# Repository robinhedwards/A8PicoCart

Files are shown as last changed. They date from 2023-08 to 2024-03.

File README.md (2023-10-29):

# A8PicoCart (UnoCart on a Raspberry Pi Pico clone)

The A8PicoCart is a multi-cart for the Atari 8-bit (XL/XE) which you can make at home with only basic soldering skills.
It is based on my earlier UnoCart design but uses a very inexpensive Raspberry Pi Pico clone (£2-3) for an easy build.

When plugged into a PC by USB it becomes a Mass Storage device allowing ROM/CAR/XEX & ATR files to be copied to the cartridge.
When plugged into an Atari these files are shown on the menu and the device will either emulate the selected cartridge type or
act as a XEX file launcher. It also has (very) limited support for ATR files allowing you to do some programming and save your
work to an ATR file.

This page contains everything you need to build the project - firmware to flash to your purple Pico clone, Kicad PCB design files to make a PCB and 3d print files for a nice case. The source code for everything is also here. There is also a manual detailing the full capabilities of the cartridge.

If you build an A8PicoCart consider donating to help fund this and my future projects:



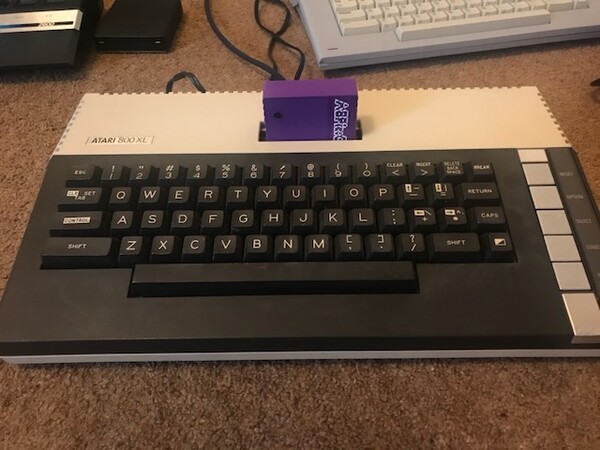
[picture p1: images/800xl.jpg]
Cased A8PicoCart in a 800xl

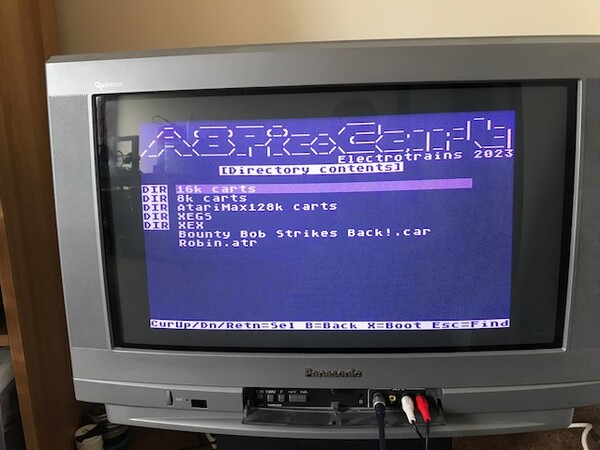
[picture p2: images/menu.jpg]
A8PicoCart Menu


## Quick Start

Get yourself a purple Raspberry Pi Pico clone (see [this thread](https://forums.raspberrypi.com/viewtopic.php?t=337976) for details) and order a PCB using the KiCad board files provided. You have a choice of two PCB designs - the XE design is for use uncased, with the Pico on the top surface. The XL/XE version is desgined to be mounted in a case (though can be used uncased too) with the Pico on the bottom/back surface. Once you have the Pico clone and PCB, solder the pico as pictured below, depending on your PCB version. Program the firmware onto the device by pressing BOOTSEL on the board and connecting to USB on a PC and drag the firmware (UF2 file) onto the device. It should then remount as A8-PICOCART so you can copy Atari CAR & XEX files to it. Unmount, then plug into your Atari and play! Optionally solder a reset button to reset back to the menu.

**Warning**: always disconnect from PC/USB before plugging into your Atari or you will damage your Atari and/or PC. This warning mainly
applies to the XE/uncased version of the PCB. The newest version of the XL/XE board makes it physically impossible to connect USB when the
cartridge is inserted in an Atari.

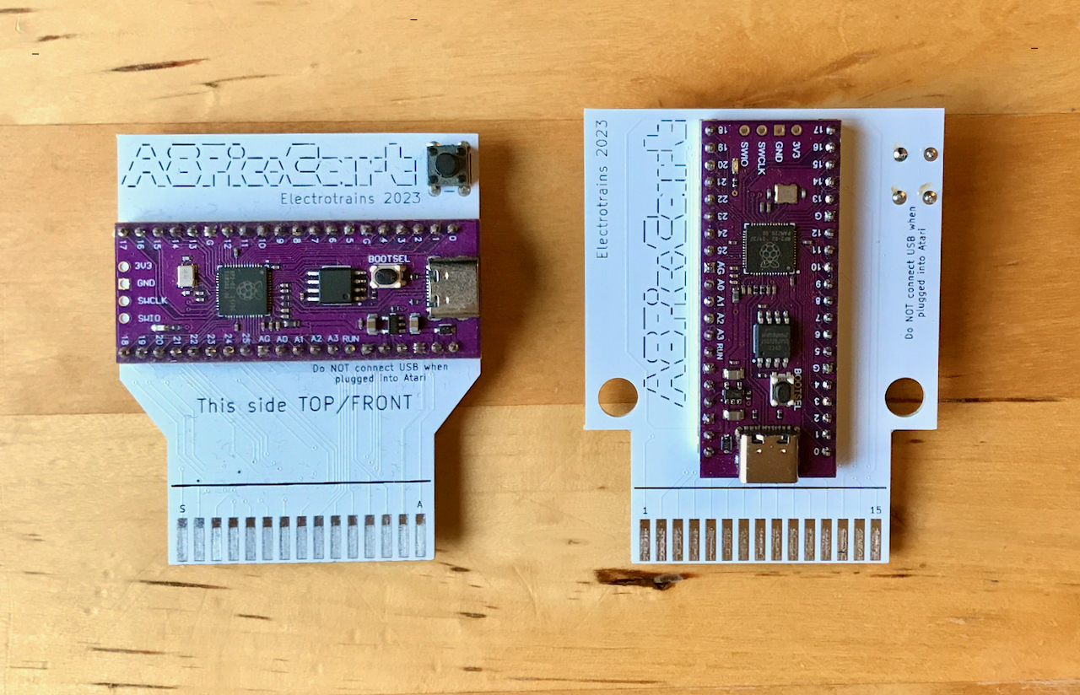
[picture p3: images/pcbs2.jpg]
Purple Pico mounted on the PCBs

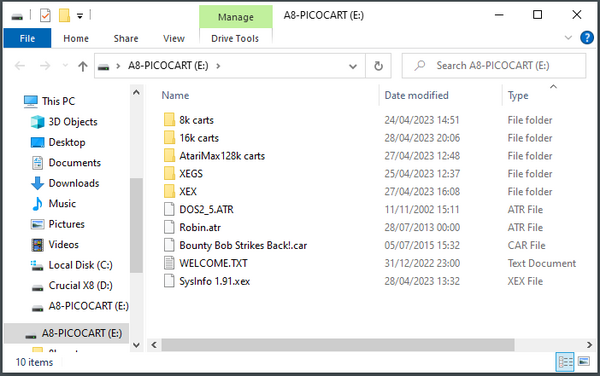
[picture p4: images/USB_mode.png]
USB Mass Storage mode


## Inserting the cartridge

Depending on which PCB you choose the Pico clone may be mounted on the front or back of the PCB. When you insert
the cartridge in the Atari make sure the "S..A" side of the cartridge edge (NOT the "1..15" side) is facing upwards (XE) or towards you (XL).

## Purple Pico clones

The firmware is designed for the Purple Pico clones with USB C connector and 16Megs of flash and a single button (BOOTSEL).
I've received these devices with two different types of SPI flash chips - Winbond and (slower) Z-bit. The firmware has been tested with both types.

The project defines a custom board with a higher value for PICO_FLASH_SPI_CLKDIV so it supports the slower Z-bit flash.

Be aware that it's possible you might get one with another type of flash memory chip that has not been tested.

## Reset button

You can solder a push button to the cartridge to get back to the menu and avoid wear on your Atari power switch.
When you reset the cartridge the Atari will crash - just push reset on the Atari itself to get back to the menu.

The button used is a 6x6mm thru-hole tactile momentary switch. If you are going to print a case, then 9mm+ height is suitable.
When you solder the button to the PCB - make sure the lower two holes in the PCB are bridged only when the button is pressed.

It works simply by pulling the RUN pin on the pico clone to ground to reset.

## 3D print files

The STL files can be used to print a 3 part (front, back and logo) cartridge shell. The 2-tone logo is achieved by
changing the filament at the correct z-position when printing a8pico_logo.stl. You'll also need two M3 15mm screws.

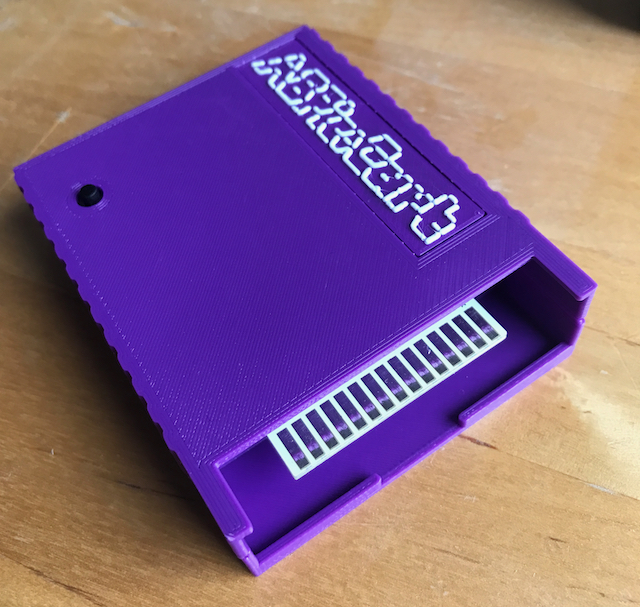
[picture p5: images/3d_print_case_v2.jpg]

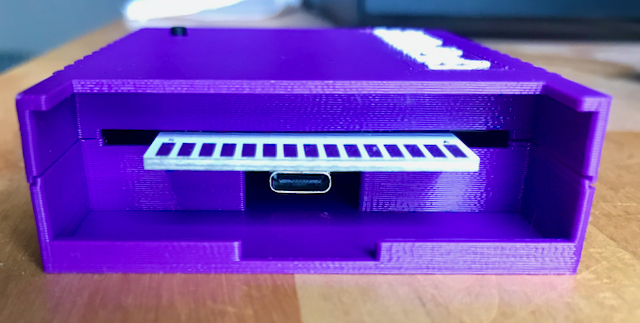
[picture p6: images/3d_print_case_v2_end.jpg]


## Changelog

* 7 Oct 2023 - Add new PCB & case design files to make it impossible to insert USB when plugged into Atari. Add support for Microcart (CAR type 52) cartridges. Updated manual.
* 29 Oct 2023 - Adds 3 new cartridge types (thanks to ascrnet)

## Credits

* Design, hardware and firmware by Robin Edwards (electrotrains at atariage)
* XEX loader and OS modifications by Jonathan Halliday (flashjazzcat at atariage)
* Altirra LLE OS used with permision from Avery Lee (phaeron at atariage)

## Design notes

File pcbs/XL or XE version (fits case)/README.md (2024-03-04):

## XL/XE version PCB (which fits the 3d printed case design)

* KiCad Project
* A zip file of the gerbers (Elecrow specification).
* Updated version for pico pointing downwards towards cartridge slot

PCB specifications:
1.6mm thickness
Hard gold fingers with bevelled edge will make your PCB last longer, but at a much higher cost.

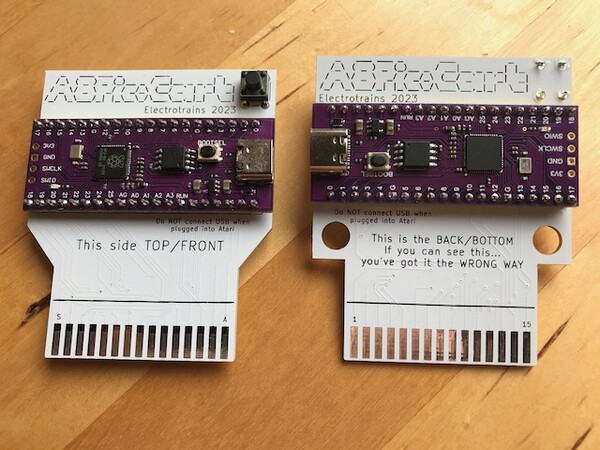
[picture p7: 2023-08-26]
images/pcbs.jpg

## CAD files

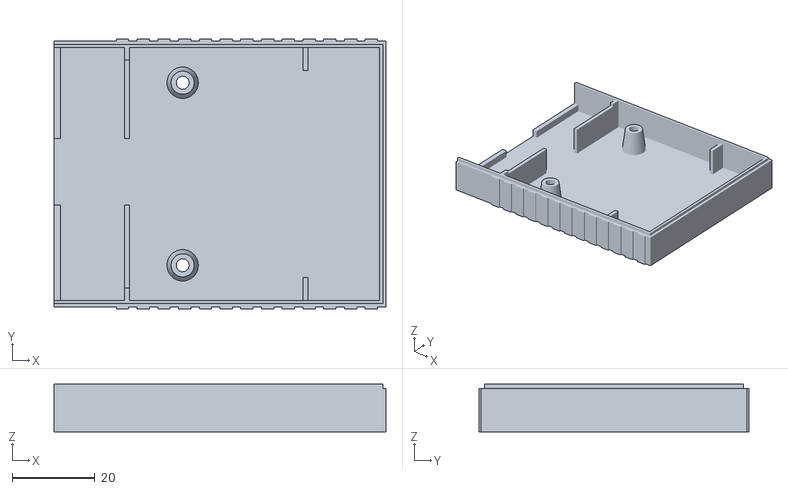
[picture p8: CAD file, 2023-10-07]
cartridge shell 3d print files/a8pico_back_v2.stl
80.0 x 65.0 x 11.5

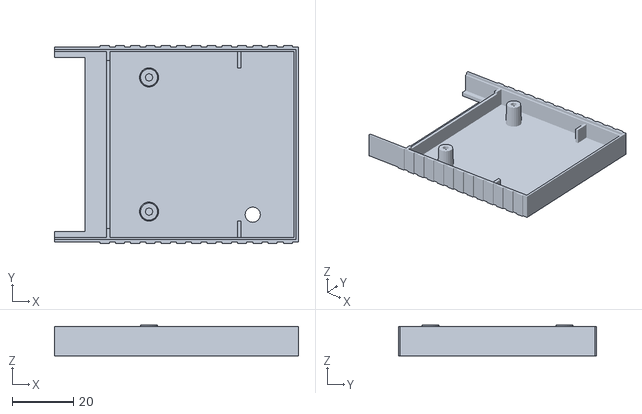
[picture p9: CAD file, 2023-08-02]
cartridge shell 3d print files/a8pico_front.stl
80.0 x 65.0 x 10.1

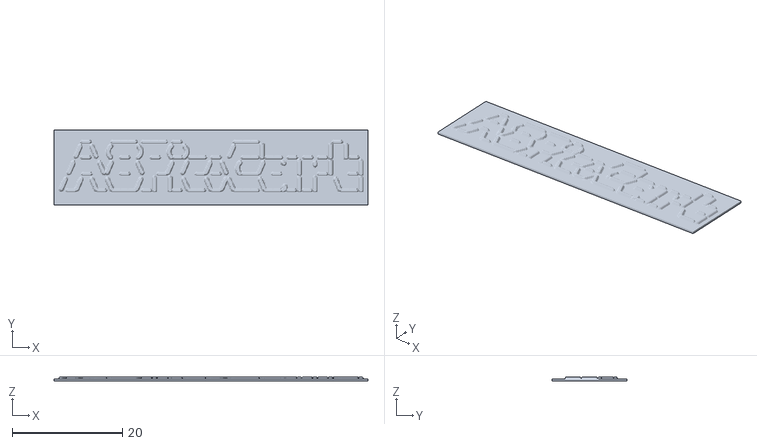
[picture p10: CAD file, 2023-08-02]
cartridge shell 3d print files/a8pico_logo.stl
57.0 x 13.7 x 0.8

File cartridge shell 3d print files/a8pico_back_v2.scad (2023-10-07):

/* A8PicoCart shell
   (c) R.Edwards 2023
*/

ridge_width = 0.5;
cart_length=80;
cart_width=65 - (ridge_width*2);
cart_height=11.5;
screw_sep = 44;
front_thickness = 1.6;
sides_thickness = 1.6 - 0.05;
support_thickness = 1.2 - 0.05;
support_height = 10.5;
rim_height=1;

difference() {
    union() {
        difference() {
            // main shell
            union() {
                cube([cart_length, cart_width, cart_height-rim_height]);
                // rim
                translate([0, sides_thickness/2, cart_height-rim_height])
                    cube([cart_length-sides_thickness/2, sides_thickness/2, rim_height]);
                translate([0, cart_width-sides_thickness, cart_height-rim_height])
                    cube([cart_length-sides_thickness/2, sides_thickness/2, rim_height]);
                translate([cart_length-sides_thickness, sides_thickness/2, cart_height-rim_height])
                    cube([sides_thickness/2, cart_width-sides_thickness, rim_height]);
            }
            // make hollow
            translate([0, sides_thickness, front_thickness])
                cube([cart_length-sides_thickness,
                    cart_width-sides_thickness*2,
                    cart_height-front_thickness]);
        }    
        // end
        cube([sides_thickness, cart_width, 4]);
        // pcb supports
        difference() {
            translate([17, sides_thickness, 0])
                cube([support_thickness, cart_width-sides_thickness*2, cart_height]);
            translate([17, (cart_width-55)/2, support_height])
                cube([support_thickness, 55, cart_height-support_height]);
        }
        translate([60, 0, 0])
            cube([support_thickness, 7, support_height]);
        translate([60, cart_width-7, 0])
            cube([support_thickness, 7, support_height]);
        // screw holes
        translate([31, (cart_width-screw_sep)/2, 0])
            difference() {
                cylinder(h = support_height - 1.2, r1 = 4, r2 = 2.8,  $fs = 1);
                cylinder(h = support_height - 1.2, r1 = 1.6, r2 = 1.6,  $fs = 1);
            }
        translate([31, cart_width-(cart_width-screw_sep)/2, 0])
            difference() {
                cylinder(h = support_height - 1.2, r1 = 4, r2 = 2.8,  $fs = 1);
                cylinder(h = support_height - 1.2, r1 = 1.6, r2 = 1.6,  $fs = 1);
            }
        // ridges
        for (i = [15: 5: cart_length-5])
            union() {
                translate([i, -ridge_width, 0])
                    cube([3, ridge_width, cart_height-rim_height]);
                translate([i, cart_width, 0])
                    cube([3, ridge_width, cart_height-rim_height]);
            }
    }
    // screw head
    translate([31, (cart_width-screw_sep)/2, 0])
        cylinder(h = 0.6, r1 = 3.5, r2 = 3.5,  $fs = 1);
    translate([31, (cart_width-screw_sep)/2, 0.6])
        cylinder(h = front_thickness-0.6, r1 = 3.5, r2 = 1.8,  $fs = 1);

    translate([31, cart_width-(cart_width-screw_sep)/2, 0])
        cylinder(h = 0.6, r1 = 3.5, r2 = 3.5,  $fs = 1);
    translate([31, cart_width-(cart_width-screw_sep)/2, 0.6])
        cylinder(h = front_thickness-0.6, r1 = 3.5, r2 = 1.8,  $fs = 1);
     // cutout USB slot
    translate([0, (cart_width-16)/2+0.5, front_thickness])    // pico is 0.5 mm off center
        cube([40, 16, cart_height]);

}

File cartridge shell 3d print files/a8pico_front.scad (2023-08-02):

/* A8PicoCart shell
   (c) R.Edwards 2023
*/

ridge_width = 0.5;
cart_length=80;
cart_width=65 - (ridge_width*2);
cart_height=9.6;
screw_sep = 44;
front_thickness = 1.6;
sides_thickness = 1.6 - 0.05;
support_thickness = 1.2 - 0.05;
support_height = 7.6;
rim_height = 1;
logo_width = 14.5;
logo_height = 58;

difference() {
    union() {
        difference() {
            // main shell
            cube([cart_length, cart_width, cart_height]);
            // rims
            translate([0, sides_thickness/2, cart_height-rim_height])
                cube([cart_length-sides_thickness/2,
                    cart_width-sides_thickness, rim_height]);
            // make hollow
            translate([0, sides_thickness, front_thickness])
                cube([cart_length-sides_thickness,
                    cart_width-sides_thickness*2,
                    cart_height-front_thickness]);
            // cutout cart port
            translate([0, (cart_width-57)/2, 0])
                cube([10, 57, cart_height]);
            // button
            translate([cart_length-15, 9, 0])
               cylinder(h = front_thickness, r1 = 2.5, r2 = 2.5,  $fs = 1); 
        }    
        // pcb supports
        difference() {
            translate([17, 0, 0])
                cube([support_thickness, cart_width, cart_height-rim_height]);
            translate([17, (cart_width-55)/2, support_height])
                cube([support_thickness, 55, cart_height-support_height]);
        }
        translate([60, 0, 0])
            cube([support_thickness, 7, support_height]);
        translate([60, cart_width-7, 0])
            cube([support_thickness, 7, support_height]);
        // screw holes
        translate([31, (cart_width-screw_sep)/2, 0])
            difference() {
                cylinder(h = support_height + 2.5, r1 = 3.2, r2 = 2.8,  $fs = 1);
                cylinder(h = support_height + 2.5, r1 = 1.25, r2 = 1.25,  $fs = 1);
            }
        translate([31, cart_width-(cart_width-screw_sep)/2, 0])
            difference() {
                cylinder(h = support_height + 2.5, r1 = 3.2, r2 = 2.8,  $fs = 1);
                cylinder(h = support_height + 2.5, r1 = 1.25, r2 = 1.25,  $fs = 1);
            }
        // ridges
        for (i = [15: 5: cart_length-5])
            union() {
                translate([i, -ridge_width, 0])
                    cube([3, ridge_width, cart_height]);
                translate([i, cart_width, 0])
                    cube([3, ridge_width, cart_height]);
            }
    }
    // logo space
    translate([cart_length-logo_height-2, cart_width-logo_width-3.5, 0])
        cube([logo_height, logo_width, 1]);
}

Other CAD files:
cartridge shell 3d print files/Previous Versions/a8pico_back.stl
cartridge shell 3d print files/a8pico_back.stl
cartridge shell 3d print files/a8pico_back.scad
cartridge shell 3d print files/Previous Versions/a8pico_back.scad

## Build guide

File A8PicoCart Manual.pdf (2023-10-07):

# Instruction Manual

Revision 3 30/9/2023

Atari XL/XE multi-cart

1

## Quick Start

The A8PicoCart is a cartridge emulator and XEX file launcher for Atari XL & XE machines supporting cartridge images and files up to 128k in size. It is a reworking of the UnoCart design for the Raspberry Pi Pico hardware.
When plugged into a PC using a USB C cable, it will appear as a USB Mass Storage device called A8-PICOCART allowing you to easily copy new Atari software to the cartridge. It has 15megs of flash storage available for Atari files.
*ALWAYS REMOVE THE CARTRIDGE FROM YOUR ATARI BEFORE PLUGGING IN A USB CABLE* Copy XEX, CAR and ROM files to the cartridge from your PC. You can create folders to organize the files. Eject the USB storage device from your PC before disconnecting the cable. Insert the cartridge in the Atari 8-bit. If the board is uncased, look for the text on the board indicating the correct orientation – the reset button should be facing forwards (Atari XL) or upwards (Atari XE). After switching on your Atari, you should see the cartridge menu screen. Use the cursor up and down keys to select an item and press Return to start it.

## Menu

The menu allows you to navigate the files on the built-in flash memory and select a title to use. Use the cursor up, down and [Return] keys to select items. Press [B] to go back to the parent directory. Press [ESC] to search for a file. Press [X] to disable the cartridge and boot normally (e.g. from a SIO device) – this allows you to leave the cartridge plugged in.

## Reset Button

Press the reset button to reset the cartridge. This will generally cause the Atari to crash, and the reset button on the Atari can then be pressed to return to the cartridge menu.

## Reset Filesystem

In the event the on-board filesystem becomes corrupted, you can reset it by holding the fire button on the first Atari joystick when you power on the Atari. Press Y in response to the prompt offering to reset the flash memory. The device will now be in a “factory” state when next used as a USB mass storage device.

## CAR Files & ROM Files

CAR files and ROM files both contain the data for a cartridge. However CAR files have an additional 16 bytes header containing the cartridge type making it clearly identifiable to the A8PicoCart. In contrast, the cartridge type of a ROM file is ambiguous – e.g. an 8k ROM file could be a standard 8K cartridge, or an 8k OSS cartridge.

## ROM Files

Plain ROM files are supported, but since these files are raw cartridge dumps, the A8PicoCart will decide what type of cartridge they come from based on the file size only. The table below shows what types will be used.
ROM File Size | Cartridge Type
8k | Standard Atari 8k
16k | Standard Atari 16k
32k | Atari XEGS 32k
64k | Atari XEGS 64k
128k | Atari XEGS 128k

2

## Supported Cartridge Types (CAR files)

Description | CAR Type(s)
Standard Atari 8k | 1
Standard Atari 16k | 2
Atari XEGS 32-128k | 12-14
AtariMax 1mbit (128k) | 41
Switchable XEGS 32-128k | 33-35
Megacart 16-128k | 26-29
Bounty Bob | 18
Williams 32k, 64k | 8, 22
OSS 8k | 44
OSS 16k (034M) | 3
OSS 16k (043M) | 45
OSS 16k (type B) | 15
SIC!Cart (128k only) | 54
SDX 64k | 11
Diamond 64k | 10
Express 64k | 9
SDX 128k | 43
Blizzard 16k | 40
4k | 58
Turbosoft 64k, 128k | 50, 51
ATRAX 128k | 17
MicroCalc/Ultracart 32k | 52

## Converting to CAR format

Utilities are available to convert ROM/BIN files into the CAR file format. The ROM2CAR utility available on the Ultimate cart website provides an easy drag and drop interface: https://github.com/robinhedwards/UltimateCart/

## Problem Files

You may come across files with a .BIN extension. These are often just .ROM files and can be renamed. You may also find ROM files where the A8PicoCart menu gives the error “Unsupported ROM size”. This happens when the ROM file is not an exact multiple of 1,024 bytes. In this case, the ROM dump may have already been converted to a CAR file (with a 16 byte header) but has been wrongly named and you can simply rename the file from .ROM to .CAR.

## ATR Files (64k and above XL/XE only)

The cartridge also has simple support for reading and writing to ATR (floppy disk image) files. It supports both SD (128 byte sector) and DD (256 byte sector) images. DD images must be standard ATR files, with 128 bytes for the first 3 sectors and no padding. The device supports ATR files up to 15 megabytes in size.
When an ATR file is selected from the menu, a modified version of the Atari operating system (OS), based on the Altirra open-source LLE kernel, is installed as a “soft” OS in the 16k RAM under the OS – this allows the Atari’s SIO requests to disk drive 1 (D1:) to be re-directed to the SD card in the cartridge.
The main use case for this feature is to allow you to boot a DOS formatted disk (e.g. DOS 2.5) and load and save BASIC programs to the disk. Note that the A8PicoCart cannot emulate a disk and cartridge at the same time.

3

Accesses to other disk drives (D2: upwards) are passed through to the SIO port as normal. This allows files to be copied between an ATR mounted on the cartridge (D1:) and other SIO devices (D2:+).
Hold down OPTION when you select the ATR file to disable BASIC. This is necessary for many games. MyPicoDOS ATRs will run, but SELECT should be pressed to disable high-speed SIO, and use the operating system SIO routines instead.
Important note – many ATRs will run correctly from the A8PicoCart. However, any programs that attempt to use the RAM under OS will not work, nor will any software that does not use the standard OS SIO calls.
The OS ROM is stored in the cartridge firmware, but an alternative UNO_OS.ROM file (16k) will be loaded and installed from the root directory of the SD card instead (if such a file is present).

## Firmware re-programming (advanced)

To program a new version of the firmware to the cart, first unscrew the cartridge shell (if present) to reveal the PCB inside. There should be a single button on the purple Pico board, marked BOOTSEL. Press and hold this button as you connect the cartridge to your PC with your USB cable. The cartridge will mount as a mass storage device, but instead of showing up as a A8-PICOCART, it should instead show as a device labelled RPI-RP2.
You can reprogram the Raspberry Pi by dragging a UF2 file into the explorer window. When the new firware has been programmed the device will dissappear, and remount as an A8-PICOCART with all files still present. The latest firmware is available on the project website: https://github.com/robinhedwards/A8PicoCart

## Microcontroller (advanced)

The A8PicoCart uses a clone of the Raspberry Pi Pico that differs from the official board by having all the RP2040 GPIO pins broken out to headers on the board. The official board has slightly too few GPIO pins available to fully connect to the Atari’s cartridge port. If you want to develop your own firmware for the device, the following table details how the cartridge port is connected to the RP2040 microcontrollers GPIO pins.

RP2040 GPIO | Cartridge Port | Function
0-12 | A0…A12 | Input - Address bus
13-20 | D0…D7 | Input/Output - Data bus
21 | /CCTL | Input - Cartridge control area access
22 | PHI2 | Input - 6502 Clock
23 | R/W | Input - 6502 Read/Write
24 | /S4 | Input - Cartridge select
25 | /S5 | Input - Cartridge select
26 (A0) | RD4 | Output – Cartridge present signal
27 (A1) | RD5 | Output – Cartridge present signal
28 (A2), 29 (A3) | | NC
RUN | | Reset Button pulls low to reset RP2040

## Credits

Original idea, hardware and firmware by Robin Edwards (electrotrains at atariage). Altirra LLE OS used with permission from Avery Lee (phaeron at atariage). XEX loader, OS modifications and many helpful discussions thanks to Jonathan Halliday (flashjazzcat at atariage).

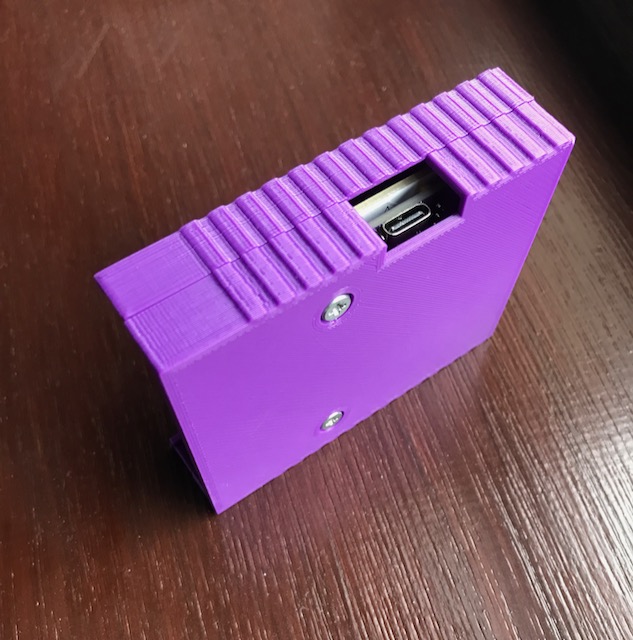
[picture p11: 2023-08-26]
images/3d_print_case_2.jpg

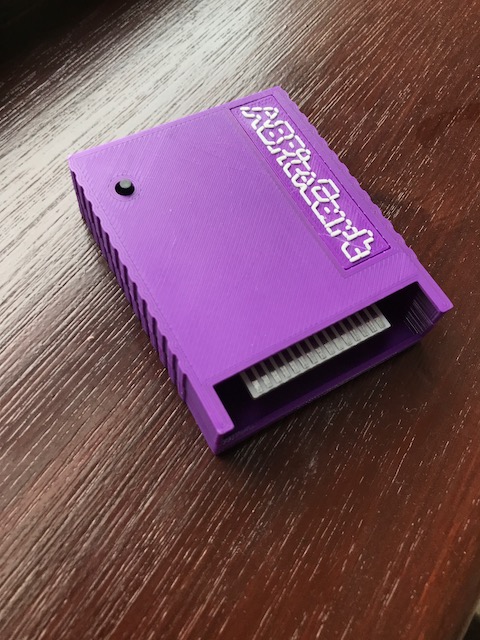
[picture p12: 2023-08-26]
images/3d_print_case_1.jpg

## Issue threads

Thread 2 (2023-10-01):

Need for removing cartridge when plugging USB cable

jhusak, 2023-10-01:
In the manual:
*ALWAYS REMOVE THE CARTRIDGE FROM YOUR ATARI BEFORE PLUGGING IN A USB CABLE*

What could happened? Was it tested and something happened? How could (cheap way) be this handled not to remove cartridge?
Removing and inserting cartridge many times is harmful either for the slot or for cartridge itself.

And in fact not the cable is a problem but adding new 5V power source from the host computer.

robinhedwards, 2023-10-01:
The risk is the USB port back-powering the Atari through the cartridge
port. There is a diode on the purple pico clone which prevents the opposite
happening. Although I haven't tested it, I would say the risk is real and
damage is likely to occur.

There is a fuller discussion of the whole issue on the AtariAge thread, and
suggestions as to how the board could be modified to remove this risk.
https://forums.atariage.com/topic/351546-a8picocart-unocart-on-a-raspberry-pi-pico/

I have solved the issue in the next version of the PCB by rotating the pico
through 90 degrees such that the USB port is facing downwards. This makes
it physically impossible to plug in USB when the cartridge is inserted.

The atari cartridge port is designed to have cartridges plugged in and
removed constantly, so I'm not worried about that. The wear to the
cartridge itself is more of a concern, I agree - but this is designed to be
a cheap and simple device.

New version of the PCB will be posted on github shortly.

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

--
Robin Edwards
email: ***@***.***
Tel: +44(0)1620 895 690
Mob: +44(0)7989 345 150

jhusak, 2023-10-01:
I think a diode from Atari 5V to pico can prevent any issues. Think of it as developing tool. You develop, upload, test. Without removing a cart. I think it is doable, or maybe I'm missing something?

robinhedwards, 2023-10-02:
Have a look at my posts on page 6 of the thread I linked on AtariAge.
A diode is not enough.

Robin

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

--
Robin Edwards
email: ***@***.***
Tel: +44(0)1620 895 690
Mob: +44(0)7989 345 150

jhusak, 2023-10-02:
So there is a try with hct4053 :) I'll watch the topic just in case.

robinhedwards, 2023-10-07:
New version of the PCB uploaded today makes it physically impossible to plug in USB cable when cartridge is inserted, so I'm going to mark this as resolved.

Closed 2023-10-07.

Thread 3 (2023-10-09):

remixed cartridge shell 3d print files

VonHirsch, 2023-10-09:
I created and uploaded a cartridge shell remix on Thingverse, letting you know in case you think it's worth linking to.  Thanks for this project!!

https://www.thingiverse.com/thing:6257150

Changes:

Moved reset hole .5 mm towards inside
Increased the diameter of the M3 screw through hole (a8pico_front)
Modified the bottom to take knurled brass threaded heat set inserts
Removed problematic gap between through-hole and thread entry

robinhedwards, 2023-11-30:
thanks!

Closed 2023-11-30.

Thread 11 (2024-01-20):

rare carts support

viktorcech, 2024-01-20:
hello, its possible add funcion to run ROM carts which have button to load? some old czechoslovakia cartridges works like that

ascrnet, 2024-03-10:
Hello I made an implementation of a timer to simulate pressing a button, it was made for turbo 2000. I attach forum thread.
https://forums.atariage.com/topic/351546-a8picocart-unocart-on-a-raspberry-pi-pico/page/19/#comment-5396027
Greetings

viktorcech, 2024-03-10:
hi, i check it, thanks
its not for turbo, but for carts like theese

viktor čech
http://turiecfoto.sk

Dňa ne 10. 3. 2024 o 19:55 Abel ***@***.***> napísala(a):

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

viktorcech, 2024-03-10:
here is a video:

https://www.youtube.com/shorts/MaE52GzUbwU

ne 10. 3. 2024 o 20:08 viktor čech ***@***.***> napísal(a):

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

--
viktor čech
http://www.starymartin.sk
http://www.turiecfoto.sk
+421 949 816 253

ascrnet, 2024-03-15:
Here you will find a compatible one

https://forums.atariage.com/topic/351546-a8picocart-unocart-on-a-raspberry-pi-pico/page/22/#comment-5429923

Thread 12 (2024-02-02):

Source code of firmware

groessler, 2024-02-02:
Hi,

is the source code of the firmware (a8_pico_cart.uf2) available somewhere?

best regards,
chris

kneehighspy, 2024-02-02:
yes,A8PicoCart/firmware at main · robinhedwards/A8PicoCartgithub.comthanks!On Feb 2, 2024, at 2:50 PM, Christian Groessler ***@***.***> wrote:
Hi,
is the source code of the firmware (a8_pico_cart.uf2) available somewhere?
best regards,
chris

—Reply to this email directly, view it on GitHub, or unsubscribe.You are receiving this because you are subscribed to this thread.Message ID: ***@***.***>

groessler, 2024-02-02:
Sorry, there's no source code. Just a binary.

kneehighspy, 2024-02-03:
A8PicoCart/source at main · robinhedwards/A8PicoCartgithub.comthanks!On Feb 2, 2024, at 3:50 PM, Christian Groessler ***@***.***> wrote:
Sorry, there's no source code. Just a binary.

—Reply to this email directly, view it on GitHub, or unsubscribe.You are receiving this because you commented.Message ID: ***@***.***>

groessler, 2024-02-03:
Hmm. Stupid me. Sure there is in "source/Pico VSCode Project/a8_pico_cart/"...

groessler, 2024-02-03:
PEBKAC error...

Closed 2024-02-03.

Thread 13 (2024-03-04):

Documentation: Specify thickness / other features of the pcb?

BrainSlugs83, 2024-03-04:
Hey,

I don't really know how to design PCBs, so maybe some of these things are specified in the file already, but usually on multi-cart projects they include information regarding what you need to specify when you order the PCB...

I'd like to order a batch of these from JLCPCB, but I have some questions that I don't see specified anywhere (at least not in English in any of the markdown files):

- Gold Fingers required? (Assuming yes; 1U?)
- Does the edge connector need beveled connections ("30 degree fingers chamfered")?  (Assuming yes)
- What is the thickness of the PCB? (seems the default is 1.6mm on JLCPCB, is that correct for this? -- or did it pick that up from the gerber file? -- is there a way I can check myself?)
- Minimum Trace Spacing?
- Castelated Holes? (Assuming no)
- Edge Plating? (assuming no)
- Any special notes we need to provide?

robinhedwards, 2024-03-04:
Agreed, I'll add this information to the PCB files readme.

In the meantime - the main thing to get right is PCB thickness of 1.6mm

Gold fingers and bevelling not required (but both would be good and aid longevity).

Robin

robinhedwards, 2024-03-04:
added thickness to pcb readme

Closed 2024-03-04.

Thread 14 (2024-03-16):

suport atari 2600 ?

manotroll, 2024-03-16:
suport atari 2600 ?

sail2themoon, 2024-06-03:
I have the very same question, and can't find an answer.. I've seen an image of a "2600 Picocard". I'm quite new to this, because I've just repaired an Atari 7800. Pls help :)

TheVintNerd, 2024-06-03:
Hi. Hopefully I can help. I did not create this project at all, but I did just post a YouTube video of soldering one together and trying it out: https://www.youtube.com/watch?v=A8cQarAvKoU

This project, the A8PicoCart, is Only for the cartridge slot of Atari 8-Bit computers (400, 800, 1200XL, 600XL, 800XL, 65XE, 130XE, 800XE, XE GS (Game System)). This project's cart will Not work with the Atari VCS/2600, 5200, 7800, etc.

Hope that helps! -Cheers, Steve aka The VintNerd on YouTube

sail2themoon, 2024-06-03:
Hi Steve,
thank you very much for bringing some light into this. Then I'll look for the 2600-version. It exists as a photo in the Atari-forum at least.

Cheers
Simon

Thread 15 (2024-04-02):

Support for the stock Pico?

modeler, 2024-04-02:
Curious to know if the stock RPi Pico (green PCB with MicroUSB) is expected to work with this board, albeit with reduced capabilities? I'm assuming not, as I have built one and there is no splash screen, just a solid colour when powering on.

I don't have any other cartridge to test with my Atari 800 XL, so just wanted to confirm. Thanks!

robinhedwards, 2024-04-02:
No - please don't try this, you'll be lucky not to break either the pico and/or your Atari 800XL, because the pinout of the two boards is quite different.

The stock/official RPi Pico doesn't break out enough of the RP2040 GPIO pins to fully connect the cartridge port, which is the main reason I chose the purple clone as a basis for this project.

Its possible to do a reduced version of the functionality with official green RPi pico (e.g. 8k cartridges), but you'd need to update both the firmware and the PCB design.

modeler, 2024-04-03:
Thanks for the quick reply and detailed explanation Robin. Might it be worth adding a note in the README to this effect? I do not have an issue with the fact that is does not work, but the potential to damage an Atari is a concern. I would not want this to come across as any sort of criticism, I fully appreciate that you shared this project with the world for free, and my misinterpretation of it is not your issue.

robinhedwards, 2024-04-03:
Thanks - I have added a note to the README as suggested. Hope your Atari is ok! Drop me a line if not, and I can probably help, since I had to replace the MMU on my own 65XE when I broke it during some early cartridge experiments.

modeler, 2024-04-03:
Thank you! It's still passing the self test but I'll keep you posted. I'm not an Atari expert, I've repaired countless Commodore 64s and own a stack of them including two I built from scratch, but I only have the one Atari 8-bit machine.

Closed 2024-04-02.

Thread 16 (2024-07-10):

max number of roms files on the pico ?

pepouille, 2024-07-10:

robinhedwards, 2024-07-10:
File storage is FAT, so there shouldn't be a practical limit to the number of files on the filesystem itself. However the A8PicoCart firmware itself will stop reading the files in a directory (for the atari menu) after 255 entries, so you need to organise files in directories if you want more than 255 files on the device.

If you are having trouble with the USB file storage, try resetting the filesystem as described in the manual?

pepouille, 2024-07-10:
yes, I've reset the board, and rearranged the files in directories, and it solved the problem I had indeed.
Thanks for your answer, and for the achieved work on this project ! ;-)

Closed 2024-07-10.

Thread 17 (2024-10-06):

Atari 8bit ram tester as NO_OS.ROM

goloskokovic, 2024-10-06:
Would it be possible to use Shoestring’s Atari 8bit ram tester instead of OS ROM?
https://jammarcade.net/shoestrings-atari-8bit-ram-tester/

This RAM test is 16k rom to be burned to 27c128 and installed in the OS socket (U5) on the Atari motherboard.
By renaming RAM test file to NO_OS.ROM in A8PicoCart can we use it to find bad DRAM?

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

robinhedwards, 2024-10-06:
From a brief scan of the code, it might work. Easiest thing to do is to try?

Regards,

Robin

On Sun, Oct 6, 2024 at 3:11 PM goloskokovic ***@***.***>
wrote:

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

--
Robin Edwards
email: ***@***.***
Tel: +44(0)1620 895 690
Mob: +44(0)7989 345 150

goloskokovic, 2024-10-14:
tried to rename file but it is ignored in root.

how do you jump here?
https://github.com/robinhedwards/A8PicoCart/blob/main/source/Pico%20VSCode%20Project/a8_pico_cart/atari_cart.c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

robinhedwards, 2024-10-14:
Try launching an ATR file. That’s what causes the soft OS to be loaded,
then a reboot should happen into the new OS

On Mon, Oct 14, 2024 at 6:42 PM goloskokovic ***@***.***>
wrote:

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

--
Robin Edwards
email: ***@***.***
Tel: +44(0)1620 895 690
Mob: +44(0)7989 345 150

goloskokovic, 2024-10-15:
when running random ATR file it starts test but freezes.

for the reference - I was able to run this test in Altirra as OS rom

goloskokovic, 2024-10-30:
I've tried to replace osrom.h with the ram_test.rom using xxd. once I built new uf2 file it behaved just as with uno_os.rom on atr load.
Can I load osrom.h before a8picocart "explorer" like [here](https://github.com/robinhedwards/A8PicoCart/blob/main/source/Pico%20VSCode%20Project/a8_pico_cart/atari_cart.c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) ?

flashjazzcat, 2024-11-07:
The loader turns off the OS ROM before loading the patched Altirra OS, and the patched OS is careful never to re-enable ROM by setting bit 0 of $D301 (PORTB). The RAM test ROM presumably assumes it's in ROM and repeatedly sets bit 0 of PORTB; this will instantly reinstate the OS ROM and cause a crash.

You'd need a special version of your RAM tester designed to run in RAM under the OS.

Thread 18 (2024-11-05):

GPIO at 5V

crystalct, 2024-11-05:
The GPIOs of the Raspberry Pico clone thus work at 5V, well above the specific 3.3V +/- 0.5V. Won't it fail in the long run?

pmandes, 2024-11-09:
Hi, Read this: https://hackaday.com/2023/04/05/rp2040-and-5v-logic-best-friends-this-fx9000p-confirms/

nanoant, 2025-01-13:
I'd like to chime in here. According to linked article "Some major points – certain GPIOs (like ADC ones) can’t take it, the GPIOs aren’t 5V-tolerant when set to output, and you shouldn’t feed the GPIOs 5V when the RP2040’s VDDIO is not powered up.".

But I can see we bind both input and output pins to directly to Atari's 5V domain. I guess if Pico fails then that's not a big loss, but what if RP2040 fails by creating short at its power line connected to more precious retro computer? I don't see short circuit protection mentioned in RT6150 SMPS IC used by Pico. Are we absolutely confident that we won't burn Atari when RP2040 fails?

There's also "caveats" link point to some discussion: https://forums.raspberrypi.com/viewtopic.php?p=2092122#p2091977

So what speaks against throwing 3 of TXS0108 other than cost of `$1.25` each `~$4` total and extra complexity in wiring everything up?

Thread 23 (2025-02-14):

Can you provide instructions for how to order the PCB?

erik-nilcoast, 2025-02-14:
I have the Gerber files from the kicad project, what do I need to do to get these fabricated?

erik-nilcoast, 2025-02-18:
https://www.youtube.com/watch?v=PQ-jYZvPYd8

Closed 2025-02-18.

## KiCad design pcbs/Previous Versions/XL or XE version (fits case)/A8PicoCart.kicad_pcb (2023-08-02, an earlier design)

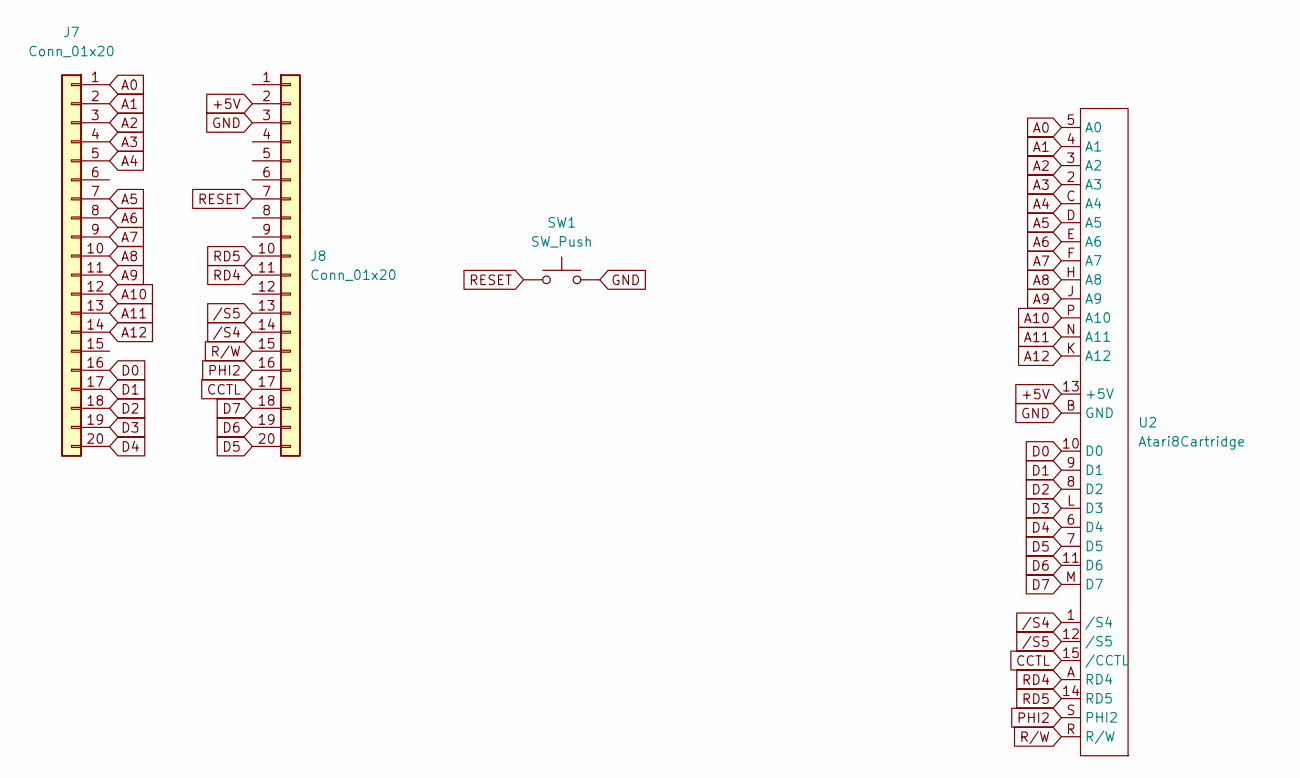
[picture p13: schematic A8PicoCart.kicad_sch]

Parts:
J7, J8: Conn_01x20; PinSocket_1x20_P2.54mm_Vertical
SW1: SW_Push; SW_PUSH_6mm_H8mm
U2: Atari8Cartridge; Atari8Cartridge MountHoles

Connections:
+5V: J8.2, U2.13 (+5V)
A0: J7.1, U2.5 (A0)
A1: J7.2, U2.4 (A1)
A2: J7.3, U2.3 (A2)
A3: J7.4, U2.2 (A3)
A4: J7.5, U2.C (A4)
A5: J7.7, U2.D (A5)
A6: J7.8, U2.E (A6)
A7: J7.9, U2.F (A7)
A8: J7.10, U2.H (A8)
A9: J7.11, U2.J (A9)
A10: J7.12, U2.P (A10)
A11: J7.13, U2.N (A11)
A12: J7.14, U2.K (A12)
CCTL: J8.17, U2.15 (/CCTL)
D0: J7.16, U2.10 (D0)
D1: J7.17, U2.9 (D1)
D2: J7.18, U2.8 (D2)
D3: J7.19, U2.L (D3)
D4: J7.20, U2.6 (D4)
D5: J8.20, U2.7 (D5)
D6: J8.19, U2.11 (D6)
D7: J8.18, U2.M (D7)
GND: J8.3, SW1.2, U2.B (GND)
PHI2: J8.16, U2.S (PHI2)
RD4: J8.11, U2.A (RD4)
RD5: J8.10, U2.14 (RD5)
RESET: J8.7, SW1.1
R/W: J8.15, U2.R (R/W)
/S4: J8.14, U2.1 (/S4)
/S5: J8.13, U2.12 (/S5)

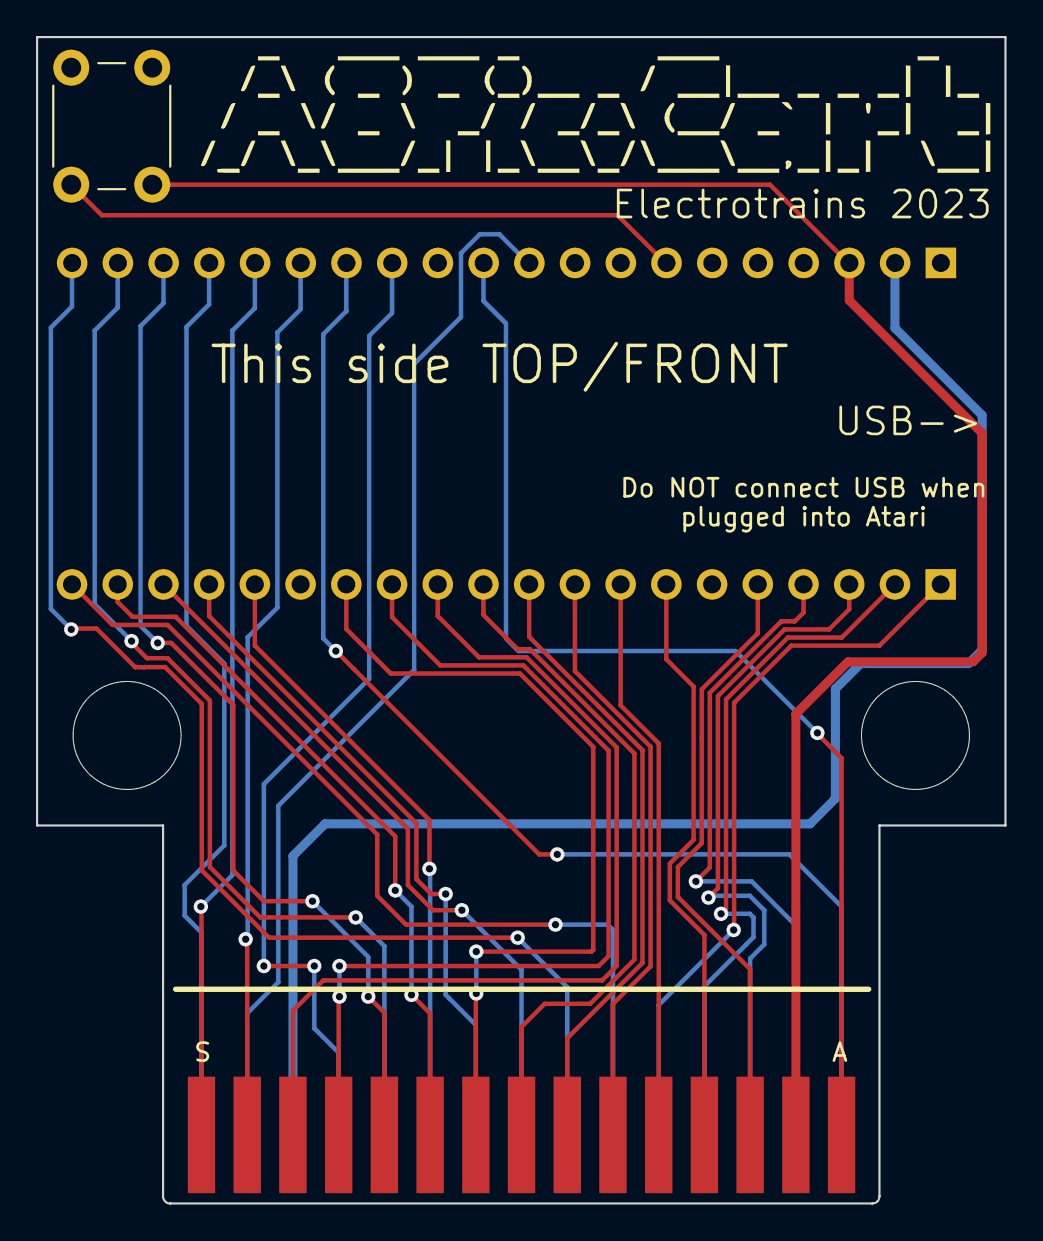
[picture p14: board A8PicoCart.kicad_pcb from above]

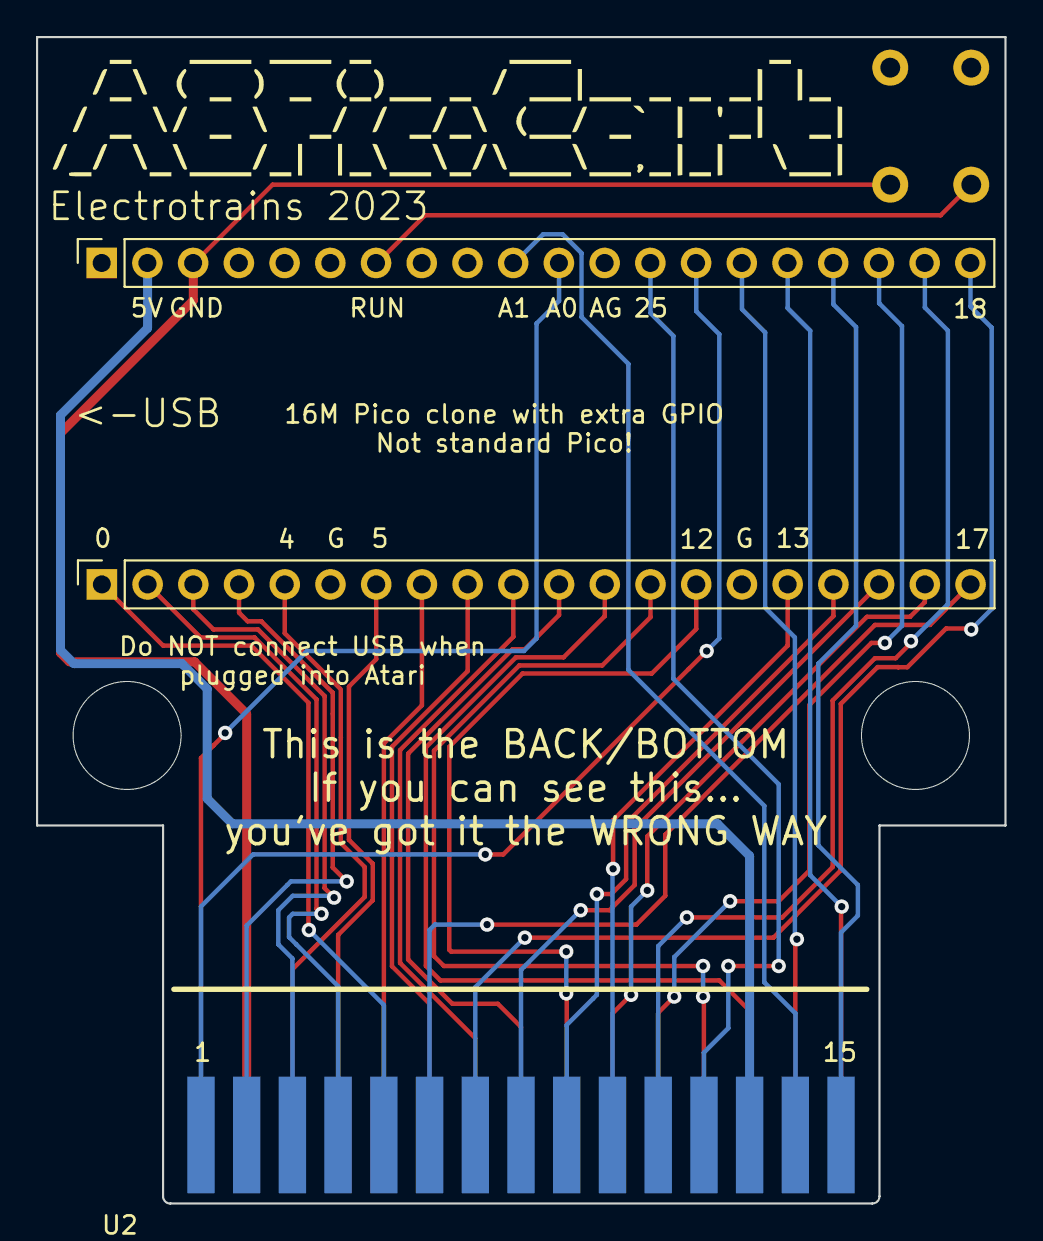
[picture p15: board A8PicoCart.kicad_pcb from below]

Board: 2 copper layers, 53.8 x 64.8 mm, 4 parts (3 on the bottom side), 31 nets.

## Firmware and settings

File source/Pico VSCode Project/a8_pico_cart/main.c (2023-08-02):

/**
 *    _   ___ ___ _       ___          _   
 *   /_\ ( _ ) _ (_)__ _ / __|__ _ _ _| |_ 
 *  / _ \/ _ \  _/ / _/_\ (__/ _` | '_|  _|
 * /_/ \_\___/_| |_\__\_/\___\__,_|_|  \__|
 *                                         
 * 
 * Atari 8-bit cartridge for Raspberry Pi Pico (16MB clone with all GPIO)
 *
 * Robin Edwards 2023
 *
 * Needs to be a release NOT debug build for the cartridge emulation to work
 * 
 * Edit myboard.h depending on the type of flash memory on the pico clone
 */

#include <stdlib.h>
#include <stdio.h>
#include <string.h>

#include "pico/stdlib.h"
#include "pico/time.h"
#include "tusb.h"

#include "atari_cart.h"
#include "fatfs_disk.h"

void cdc_task(void);

int main(void)
{
    // check to see if we are plugged into Atari 8-bit
    // by checking for high on PHI2 gpio for 100ms
    gpio_init(ATARI_PHI2_PIN);
    gpio_set_dir(ATARI_PHI2_PIN, GPIO_IN);
    while (to_ms_since_boot(get_absolute_time()) < 100)
    {
      if (gpio_get(ATARI_PHI2_PIN))
        atari_cart_main();
    }

  // we are presumably powered from USB
  // enter USB mass storage mode

  stdio_init_all();   // for serial output, via printf()
  printf("Start up\n");  

  // init device stack on configured roothub port
  tud_init(BOARD_TUD_RHPORT);

  while (1)
  {
    tud_task(); // tinyusb device task

    cdc_task();
  }

  return 0;
}

//--------------------------------------------------------------------+
// Device callbacks
//--------------------------------------------------------------------+

// Invoked when device is mounted
void tud_mount_cb(void)
{
  printf("Device mounted\n"); 
  if (!mount_fatfs_disk())
    create_fatfs_disk();
}

// Invoked when device is unmounted
void tud_umount_cb(void)
{
  printf("Device unmounted\n");  
}

// Invoked when usb bus is suspended
// remote_wakeup_en : if host allow us  to perform remote wakeup
// Within 7ms, device must draw an average of current less than 2.5 mA from bus
void tud_suspend_cb(bool remote_wakeup_en)
{
  (void) remote_wakeup_en;
//  blink_interval_ms = BLINK_SUSPENDED;
}

// Invoked when usb bus is resumed
void tud_resume_cb(void)
{
//  blink_interval_ms = BLINK_MOUNTED;
}


//--------------------------------------------------------------------+
// USB CDC
//--------------------------------------------------------------------+
void cdc_task(void)
{
  // connected() check for DTR bit
  // Most but not all terminal client set this when making connection
  // if ( tud_cdc_connected() )
  {
    // connected and there are data available
    if ( tud_cdc_available() )
    {
      // read data
      char buf[64];
      uint32_t count = tud_cdc_read(buf, sizeof(buf));
      (void) count;

      // Echo back
      // Note: Skip echo by commenting out write() and write_flush()
      // for throughput test e.g
      //    $ dd if=/dev/zero of=/dev/ttyACM0 count=10000
      tud_cdc_write(buf, count);
      tud_cdc_write_flush();
    }
  }
}

// Invoked when cdc when line state changed e.g connected/disconnected
void tud_cdc_line_state_cb(uint8_t itf, bool dtr, bool rts)
{
  (void) itf;
  (void) rts;

  // TODO set some indicator
  if ( dtr )
  {
    // Terminal connected
  }else
  {
    // Terminal disconnected
  }
}

// Invoked when CDC interface received data from host
void tud_cdc_rx_cb(uint8_t itf)
{
  (void) itf;
}

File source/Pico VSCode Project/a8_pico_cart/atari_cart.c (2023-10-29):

/**
 *    _   ___ ___ _       ___          _   
 *   /_\ ( _ ) _ (_)__ _ / __|__ _ _ _| |_ 
 *  / _ \/ _ \  _/ / _/_\ (__/ _` | '_|  _|
 * /_/ \_\___/_| |_\__\_/\___\__,_|_|  \__|
 *                                         
 * 
 * Atari 8-bit cartridge for Raspberry Pi Pico
 *
 * Robin Edwards 2023
 *
 * Needs to be a release NOT debug build for the cartridge emulation to work
 * 
 * Changes from UnoCart:
 * - Attempts to get S4/S5, RD4/RD5 MMU behaviour correct on 400/800
 *   https://forums.atariage.com/topic/241888-ultimate-cart-sd-multicart-technical-thread/page/10/#comment-4266797
 * - Adds 4k carts (CAR type 58)
 * - Adds Turbsoft carts (CAR types 50,51)
 * - Adds ATRAX 128k carts (CAR type 17)
 * - Adds Microcalc/Utracart (CAR type 52)
 * - Adds Standard 2k cars (CAR type 57)
 * - Adds Phoenix 8k cars (CAR type 39)
 * - Adds Blizzard 4k cars (CAR type 46)
 */

#include <string.h>
#include <stdlib.h>

#include "pico/stdlib.h"
#include "hardware/sync.h"

#include "ff.h"
#include "fatfs_disk.h"

#define ALL_GPIO_MASK   	0x3FFFFFFF
#define ADDR_GPIO_MASK  	0x00001FFF
#define DATA_GPIO_MASK  	0x001FE000
#define CCTL_GPIO_MASK  	0x00200000  // gpio 21
#define PHI2_GPIO_MASK  	0x00400000  // gpio 22
#define RW_GPIO_MASK    	0x00800000  // gpio 23
#define S4_GPIO_MASK    	0x01000000  // gpio 24
#define S5_GPIO_MASK    	0x02000000  // gpio 25

#define S4_S5_GPIO_MASK 	0x03000000
#define CCTL_RW_GPIO_MASK 	0x00A00000

#define RD4_PIN         26
#define RD5_PIN         27

#define RD4_LOW             gpio_put(RD4_PIN, 0)
#define RD4_HIGH            gpio_put(RD4_PIN, 1)
#define RD5_LOW             gpio_put(RD5_PIN, 0)
#define RD5_HIGH            gpio_put(RD5_PIN, 1)
#define SET_DATA_MODE_OUT   gpio_set_dir_out_masked(DATA_GPIO_MASK)
#define SET_DATA_MODE_IN    gpio_set_dir_in_masked(DATA_GPIO_MASK)

#include "rom.h"
#include "osrom.h"

unsigned char cart_ram[128*1024];
unsigned char cart_d5xx[256] = {0};
char errorBuf[40];

#define CART_CMD_OPEN_ITEM			0x00
#define CART_CMD_READ_CUR_DIR		0x01
#define CART_CMD_GET_DIR_ENTRY		0x02
#define CART_CMD_UP_DIR				0x03
#define CART_CMD_ROOT_DIR			0x04
#define CART_CMD_SEARCH				0x05
#define CART_CMD_LOAD_SOFT_OS		0x10
#define CART_CMD_SOFT_OS_CHUNK		0x11
#define CART_CMD_MOUNT_ATR			0x20	// unused, done automatically by firmware
#define CART_CMD_READ_ATR_SECTOR	0x21
#define CART_CMD_WRITE_ATR_SECTOR	0x22
#define CART_CMD_ATR_HEADER			0x23
#define CART_CMD_RESET_FLASH		0xF0
#define CART_CMD_NO_CART			0xFE
#define CART_CMD_ACTIVATE_CART  	0xFF

#define CART_TYPE_NONE				0
#define CART_TYPE_8K				1	// 8k
#define CART_TYPE_16K				2	// 16k
#define CART_TYPE_XEGS_32K			3	// 32k
#define CART_TYPE_XEGS_64K			4	// 64k
#define CART_TYPE_XEGS_128K			5	// 128k
#define CART_TYPE_SW_XEGS_32K		6	// 32k
#define CART_TYPE_SW_XEGS_64K		7	// 64k
#define CART_TYPE_SW_XEGS_128K		8	// 128k
#define CART_TYPE_MEGACART_16K		9	// 16k
#define CART_TYPE_MEGACART_32K		10	// 32k
#define CART_TYPE_MEGACART_64K		11	// 64k
#define CART_TYPE_MEGACART_128K		12	// 128k
#define CART_TYPE_BOUNTY_BOB		13	// 40k
#define CART_TYPE_ATARIMAX_1MBIT	14	// 128k
#define CART_TYPE_WILLIAMS_64K		15	// 32k/64k
#define CART_TYPE_OSS_16K_TYPE_B	16	// 16k
#define CART_TYPE_OSS_8K			17	// 8k
#define CART_TYPE_OSS_16K_034M		18	// 16k
#define CART_TYPE_OSS_16K_043M		19	// 16k
#define CART_TYPE_SIC_128K			20	// 128k
#define CART_TYPE_SDX_64K			21	// 64k
#define CART_TYPE_SDX_128K			22	// 128k
#define CART_TYPE_DIAMOND_64K		23	// 64k
#define CART_TYPE_EXPRESS_64K		24	// 64k
#define CART_TYPE_BLIZZARD_16K		25	// 16k
#define CART_TYPE_4K				26	// 4k
#define CART_TYPE_TURBOSOFT_64K		27	// 64k
#define CART_TYPE_TURBOSOFT_128K	28	// 128k
#define CART_TYPE_ATRAX_128K		29	// 128k
#define CART_TYPE_MICROCALC			30	// 32k
#define CART_TYPE_2K				31  // 2k
#define CART_TYPE_PHOENIX_8K		32	// 8k
#define CART_TYPE_BLIZZARD_4K		33	// 4k
#define CART_TYPE_ATR				254
#define CART_TYPE_XEX				255

typedef struct {
	char isDir;
	char filename[13];
	char long_filename[32];
	char full_path[210];
} DIR_ENTRY;	// 256 bytes = 256 entries in 64k

int num_dir_entries = 0; // how many entries in the current directory

int entry_compare(const void* p1, const void* p2)
{
	DIR_ENTRY* e1 = (DIR_ENTRY*)p1;
	DIR_ENTRY* e2 = (DIR_ENTRY*)p2;
	if (e1->isDir && !e2->isDir) return -1;
	else if (!e1->isDir && e2->isDir) return 1;
	else return strcasecmp(e1->long_filename, e2->long_filename);
}

char *get_filename_ext(char *filename) {
    char *dot = strrchr(filename, '.');
    if(!dot || dot == filename) return "";
    return dot + 1;
}

int is_valid_file(char *filename) {
	char *ext = get_filename_ext(filename);
	if (strcasecmp(ext, "CAR") == 0 || strcasecmp(ext, "ROM") == 0
			|| strcasecmp(ext, "XEX") == 0 || strcasecmp(ext, "ATR") == 0)
		return 1;
	return 0;
}

FILINFO fno;
char search_fname[FF_LFN_BUF + 1];

// polyfill :-)
char *stristr(const char *str, const char *strSearch) {
    char *sors, *subs, *res = NULL;
    if ((sors = strdup (str)) != NULL) {
        if ((subs = strdup (strSearch)) != NULL) {
            res = strstr (strlwr (sors), strlwr (subs));
            if (res != NULL)
                res = (char*)str + (res - sors);
            free (subs);
        }
        free (sors);
    }
    return res;
}

int scan_files(char *path, char *search)
{
    FRESULT res;
    DIR dir;
    UINT i;

	res = f_opendir(&dir, path);
	if (res == FR_OK) {
		for (;;) {
			if (num_dir_entries == 255) break;
			res = f_readdir(&dir, &fno);
			if (res != FR_OK || fno.fname[0] == 0) break;
			if (fno.fattrib & (AM_HID | AM_SYS)) continue;
			if (fno.fattrib & AM_DIR) {
				i = strlen(path);
				strcat(path, "/");
				if (fno.altname[0])	// no altname when lfn is 8.3
					strcat(path, fno.altname);
				else
					strcat(path, fno.fname);
				if (strlen(path) >= 210) continue;	// no more room for path in DIR_ENTRY
				res = scan_files(path, search);
				if (res != FR_OK) break;
				path[i] = 0;
			}
			else if (is_valid_file(fno.fname))
			{
				char *match = stristr(fno.fname, search);
				if (match) {
					DIR_ENTRY *dst = (DIR_ENTRY *)&cart_ram[0];
					dst += num_dir_entries;
					// fill out a record
					dst->isDir = (match == fno.fname) ? 1 : 0;	// use this for a "score"
					strncpy(dst->long_filename, fno.fname, 31);
					dst->long_filename[31] = 0;
					// 8.3 name
					if (fno.altname[0])
						strcpy(dst->filename, fno.altname);
					else {	// no altname when lfn is 8.3
						strncpy(dst->filename, fno.fname, 12);
						dst->filename[12] = 0;
					}
					// full path for search results
					strcpy(dst->full_path, path);

					num_dir_entries++;
				}
			}
		}
		f_closedir(&dir);
	}
	return res;
}
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

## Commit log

2023-08-02 initial commit of all source files
    [A8PicoCart.kicad_pcb, A8PicoCart.kicad_sch, a8pico_back.scad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]
2023-08-03 reorganise files
    [A8PicoCart.kicad_pcb, A8PicoCart.kicad_sch, a8pico_back.scad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]
2023-08-27 add screw specs
2023-08-27 add gerbers
2023-10-07 update pcb, case
    remove risk of back powering atari from USB by making it physically impossible on the XL/XE/cased board
    [A8PicoCart.kicad_pcb, A8PicoCart.kicad_sch, a8pico_back.scad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]
2024-03-04 Update README.md
    add PCB thickness
